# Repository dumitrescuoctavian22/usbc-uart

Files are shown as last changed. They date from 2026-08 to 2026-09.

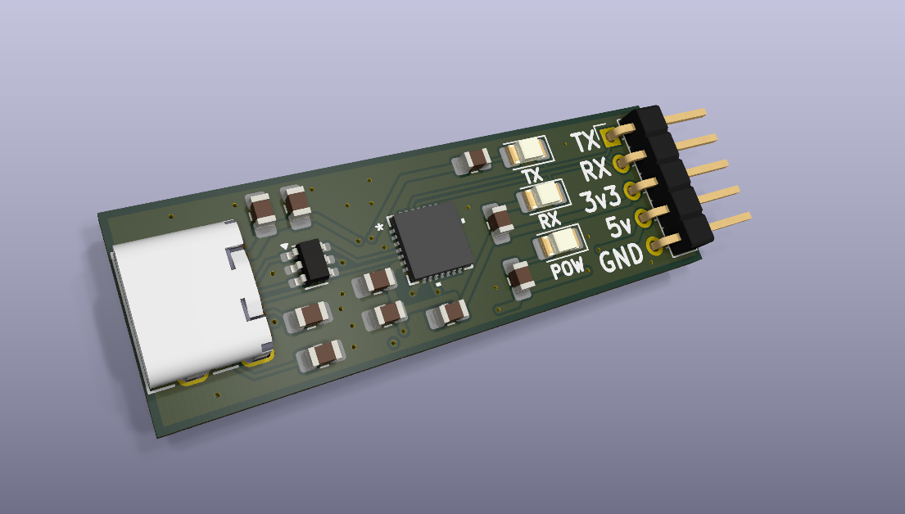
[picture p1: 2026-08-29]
images/3d-render.PNG

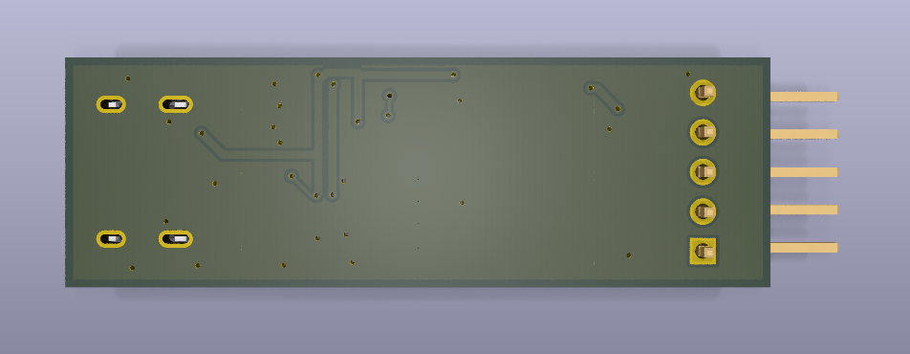
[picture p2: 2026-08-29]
images/3d-render/render-back.PNG

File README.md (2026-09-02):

USB-C → UART Adapter

A compact USB-C to UART adapter designed around the CP2102 USB-to-UART bridge. The board provides a simple interface for connecting a computer to microcontrollers and other embedded systems through a standard UART interface.

The PCB was designed from schematic to layout in KiCad as a 2-layer board, with USB 2.0 connectivity, ESD protection, status LEDs, and an accessible UART header.

Features

- USB-C input
- CP2102 USB-to-UART bridge
- USB 2.0 interface
- USB ESD protection using ST USBLC6-2SC6
- 5-pin UART header
- Power and UART activity indicators
- 2-layer PCB
- Designed in KiCad

UART Header

The UART interface is exposed through a 5-pin header:

Pin| Function
1| RX

2| TX

3| 3V3

4| 5V

5| GND

USB-C Interface

The board uses a 16-pin USB-C receptacle for USB 2.0 communication.

The USB interface includes the USB data lines, power connections, and USB-C configuration connections. ESD protection is provided by the ST USBLC6-2SC6, protecting the USB data interface against electrostatic discharge.

USB-to-UART Conversion

The CP2102 is the main USB-to-UART bridge on the board.

It handles the conversion between USB communication from the host computer and the UART interface exposed on the header.

The board is intended to provide a convenient interface for development, debugging, and communication with embedded systems.

Status LEDs

Three LEDs are included on the board:

LED  | Color | Function

Power| Green | Power indication

RX   | Red   | UART receive activity

TX   | Yellow| UART transmit activity

These indicators provide visual feedback for power and UART communication.

PCB Design

The PCB was designed as a 2-layer board in KiCad.

The design process included:

- Schematic capture
- Component selection
- USB-C interface design
- USB ESD protection
- CP2102 USB-to-UART implementation
- Component placement
- PCB routing
- Power distribution
- UART header layout
- 3D PCB visualization

Particular attention was given to keeping the USB interface compact and placing the ESD protection around the USB connection.

Repository Structure

usbc-uart/

├── README.md

├── documentation/

├── hardware/

├── images/

└── manufacturing/

The repository contains the KiCad hardware design files, documentation, images, and manufacturing-related files.

Tools

- KiCad — schematic and PCB design
- KiCad 3D Viewer — PCB visualization

Project Status

PCB designed — not yet manufactured or tested.

This project currently represents the completed PCB design and serves as a practical demonstration of USB-C interfacing, USB-to-UART conversion, ESD protection, component placement, and 2-layer PCB routing.

What I Learned

This project was created to develop practical PCB design skills while working with a real USB interface and USB-to-UART bridge.

The main areas explored were:

- USB-C connector implementation
- USB 2.0 interface design
- USB ESD protection
- CP2102 integration
- UART interface design
- Power distribution
- PCB component placement
- 2-layer PCB routing
- KiCad schematic-to-PCB workflow
- PCB documentation and organization

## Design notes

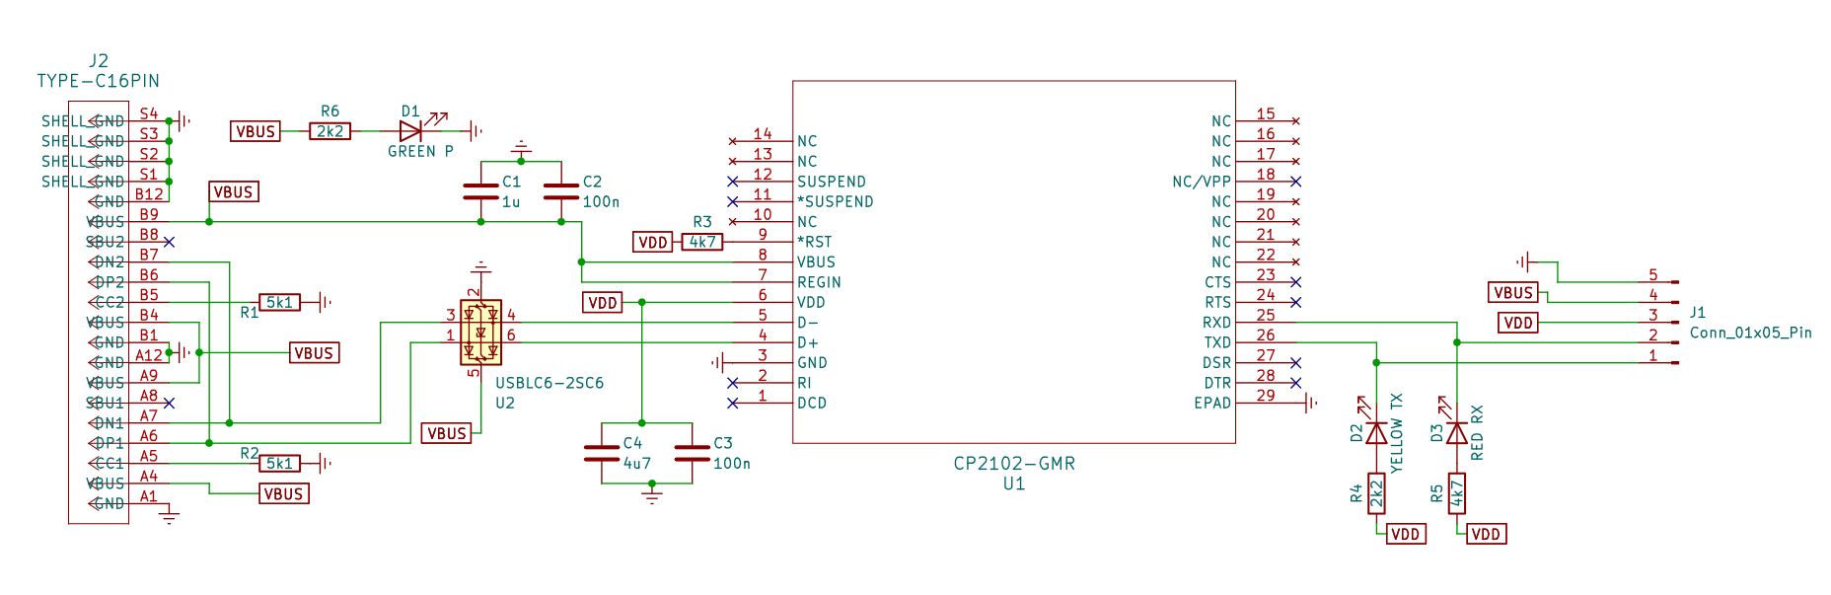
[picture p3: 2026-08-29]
images/schematic.PNG

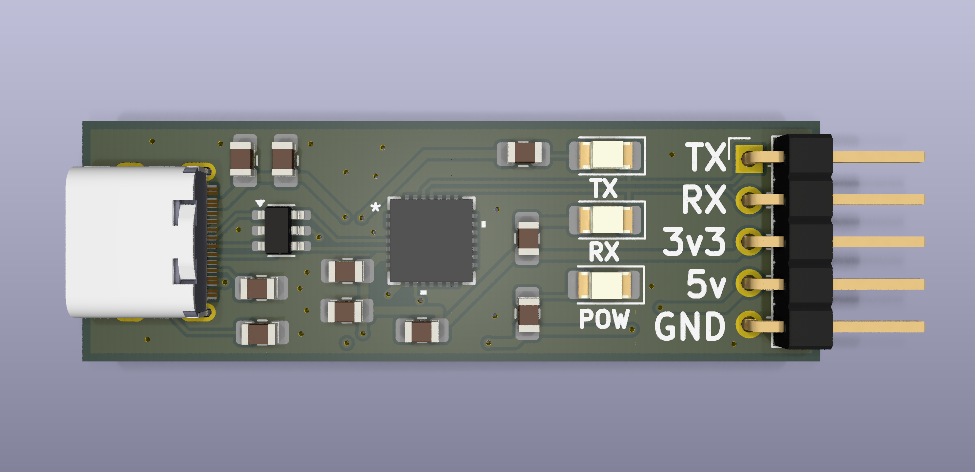
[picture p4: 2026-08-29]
images/3d-render/render-front.PNG

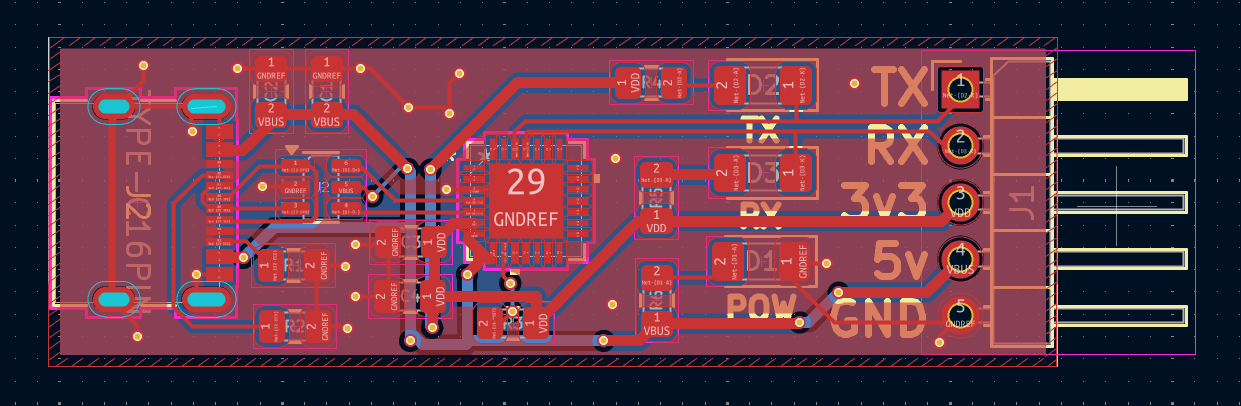
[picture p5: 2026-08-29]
images/pcb.PNG

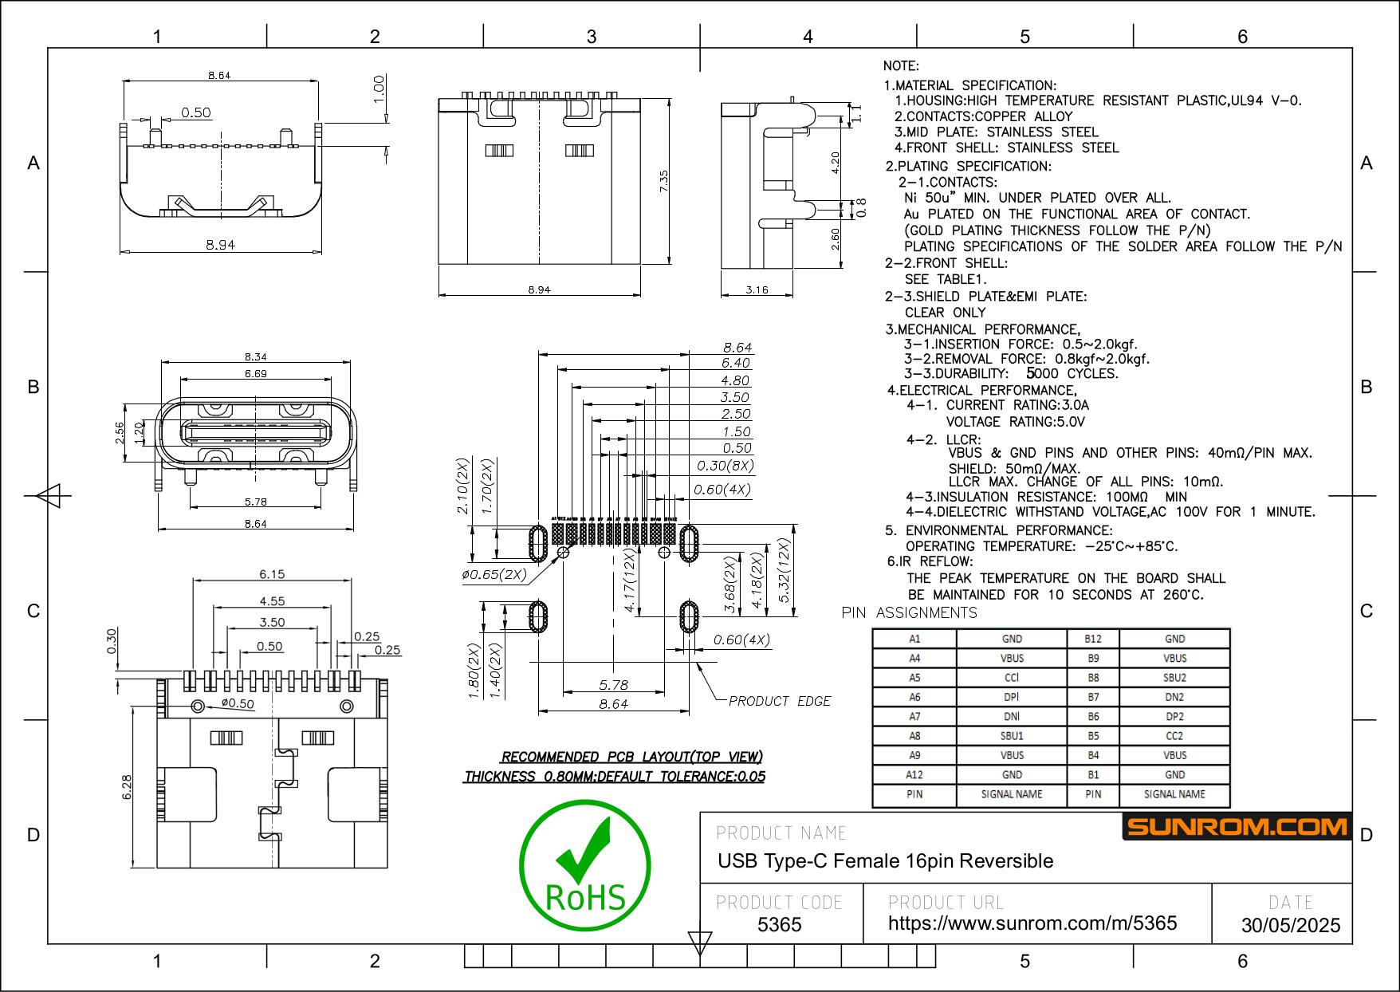
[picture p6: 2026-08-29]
documentation/usbc-female-port.jpg

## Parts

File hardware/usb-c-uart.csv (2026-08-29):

Reference | Value | Footprint | Datasheet | Qty | DNP | Exclude from BOM | Exclude from Board
C1 | 1u | Capacitor_SMD:C_0805_2012Metric_Pad1.18x1.45mm_HandSolder | ~ | 1
C2,C3 | 100n | Capacitor_SMD:C_0805_2012Metric_Pad1.18x1.45mm_HandSolder | ~ | 2
C4 | 4u7 | Capacitor_SMD:C_0805_2012Metric_Pad1.18x1.45mm_HandSolder | ~ | 1
D1 | GREEN P | LED_SMD:LED_1206_3216Metric_Pad1.42x1.75mm_HandSolder | ~ | 1
D2 | YELLOW TX | LED_SMD:LED_1206_3216Metric_Pad1.42x1.75mm_HandSolder | ~ | 1
D3 | RED RX | LED_SMD:LED_1206_3216Metric_Pad1.42x1.75mm_HandSolder | ~ | 1
J1 | Conn_01x05_Pin | Connector_PinHeader_2.54mm:PinHeader_1x05_P2.54mm_Horizontal | ~ | 1
J2 | TYPE-C16PIN | 1A:CONN16_C16PIN_SHN | TYPE-C16PIN | 1
R1,R2 | 5k1 | Capacitor_SMD:C_0805_2012Metric_Pad1.18x1.45mm_HandSolder | ~ | 2
R3,R5 | 4k7 | Capacitor_SMD:C_0805_2012Metric_Pad1.18x1.45mm_HandSolder | ~ | 2
R4,R6 | 2k2 | Capacitor_SMD:C_0805_2012Metric_Pad1.18x1.45mm_HandSolder | ~ | 2
U1 | CP2102-GMR | 1A:QFN28_5X5_SIL | CP2102-GMR | 1
U2 | USBLC6-2SC6 | Package_TO_SOT_SMD:SOT-23-6 | https://www.st.com/resource/en/datasheet/usblc6-2.pdf | 1

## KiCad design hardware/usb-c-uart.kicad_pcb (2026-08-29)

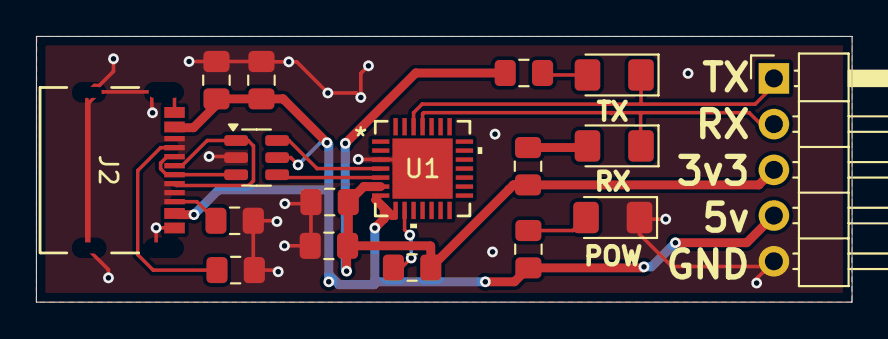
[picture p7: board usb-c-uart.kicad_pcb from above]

Board: 2 copper layers, 45.3 x 14.8 mm, 17 parts (0 on the bottom side), 15 nets.

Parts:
C1: 1u; C_0805_2012Metric_Pad1.18x1.45mm_HandSolder
C2, C3: 100n; C_0805_2012Metric_Pad1.18x1.45mm_HandSolder
C4: 4u7; C_0805_2012Metric_Pad1.18x1.45mm_HandSolder
D1: GREEN P; LED_1206_3216Metric_Pad1.42x1.75mm_HandSolder
D2: YELLOW TX; LED_1206_3216Metric_Pad1.42x1.75mm_HandSolder
D3: RED RX; LED_1206_3216Metric_Pad1.42x1.75mm_HandSolder
J1: Conn_01x05_Pin; PinHeader_1x05_P2.54mm_Horizontal
J2: TYPE-C16PIN; CONN16_C16PIN_SHN
R1, R2: 5k1; C_0805_2012Metric_Pad1.18x1.45mm_HandSolder
R3, R5: 4k7; C_0805_2012Metric_Pad1.18x1.45mm_HandSolder
R4, R6: 2k2; C_0805_2012Metric_Pad1.18x1.45mm_HandSolder
U1: CP2102-GMR; QFN28_5X5_SIL
U2: USBLC6-2SC6; SOT-23-6

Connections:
GNDREF: C1.1, C2.1, C3.2, C4.2, D1.1 (K), J1.5, J2.A1 (GND), J2.A12 (GND), J2.B1 (GND), J2.B12 (GND), R1.2, R2.2, U1.3 (GND), U1.29 (EPAD), U2.2 (GND)
unnamed: D1.2 (A), R6.2
unnamed: D2.2 (A), R4.2
unnamed: D2.1 (K), J1.1, U1.26 (TXD)
unnamed: D3.2 (A), R5.2
unnamed: D3.1 (K), J1.2, U1.25 (RXD)
unnamed: J2.A5 (CC1), R2.1
unnamed: J2.B5 (CC2), R1.1
unnamed: J2.A7 (DN1), J2.B7 (DN2), U2.3 (I/O2)
unnamed: J2.A6 (DP1), J2.B6 (DP2), U2.1 (I/O1)
unnamed: R3.2, U1.9 (*RST)
unnamed: U1.4 (D+), U2.6 (I/O1)
unnamed: U1.5 (D-), U2.4 (I/O2)
VBUS: C1.2, C2.2, J1.4, J2.A4 (VBUS), J2.A9 (VBUS), J2.B4 (VBUS), J2.B9 (VBUS), R6.1, U1.7 (REGIN), U1.8 (VBUS), U2.5 (VBUS)
VDD: C3.1, C4.1, J1.3, R3.1, R4.1, R5.1, U1.6 (VDD)

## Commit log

2026-08-29 Added hardware folder (sch, pcb, bom)
    [usb-c-uart.csv, usb-c-uart.kicad_pcb, usb-c-uart.kicad_sch]
2026-08-29 Added manufacturing file (gerber, drill)
    [usb-c-uart-B_Cu.gbr, usb-c-uart-B_Mask.gbr, usb-c-uart-B_Paste.gbr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]
